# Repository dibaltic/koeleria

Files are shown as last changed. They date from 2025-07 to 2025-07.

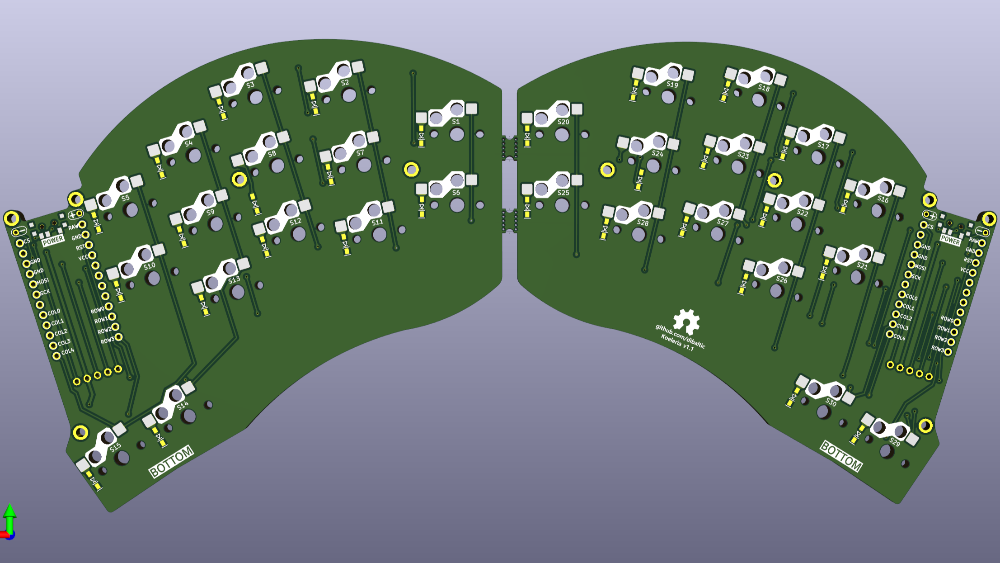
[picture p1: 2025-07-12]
PCB/images/bottomPCB.png

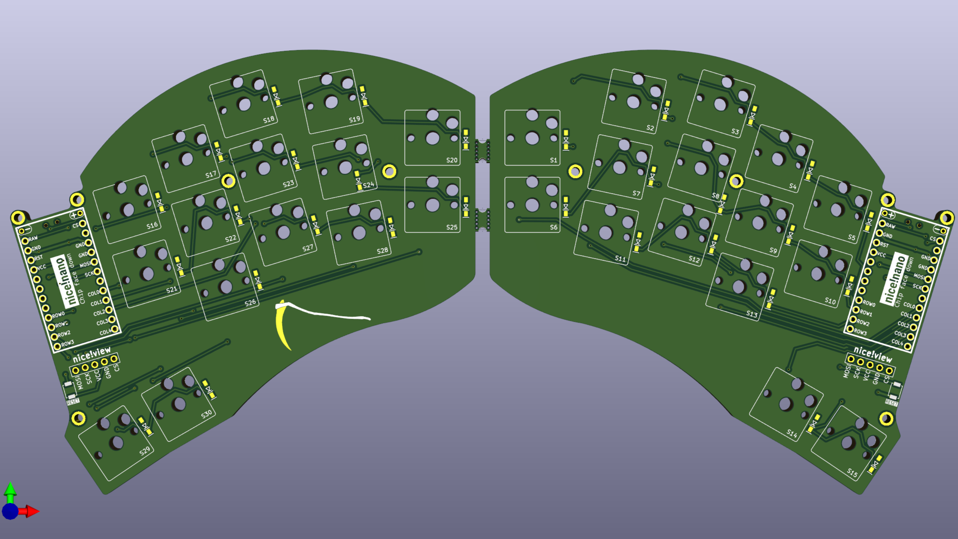
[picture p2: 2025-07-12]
PCB/images/topPCB.png

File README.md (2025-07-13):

# Koeleria
WithWithoutDisplay
CaseAngled

## Features
- 30 keys with splay and column stagger
- nice!view and nice!nano
- Hotswap sockets, no direct solder option for switches
- Low profile Choc V1 switches with Choc spacing
- Exclusively wireless using [ZMK firmware](https://zmk.dev/)
- Cases are designed to be low profile with recessed adhesive feet
- A variety of cases can be found in the [3d_Print](https://github.com/dibaltic/koeleria/tree/main/3d_Print) folder. Including enclosed split, minimal split, unibody, storage case, and variety of tenting angles.

SideProfile

### Design

- My first ergo keyboard was an MX Sweep, and then shortly after a wireless Choc Sweep. I wanted my thumbs less tucked, to use my pinky less, and reach less with my index finger. I also wanted to have the option for a display. 

- My goal was to make keyboard to be as low profile as I could. The case adds 1mm in height to the PCB. There is a total of 1.5mm added height with the specified silicone feet installed on the case.

- In the majority of the photos I am using [KLP Lamé](https://github.com/braindefender/KLP-Lame-Keycaps) keycaps with LSDA profile thumbs, but the case was designed around clearing normal keycaps as you can see in the photos of the unibody case with a full set LSDA keycaps installed.

- All the files for the keyboard and cases have been shared if you would like to modify anything to better suit your needs.

MinimalAndEnclosed

# B.O.M 

#### Required

- 1x PCB pair (production files can be found [here](https://github.com/dibaltic/koeleria/tree/main/PCB/Gerbers))
- 30x Kailh Choc V1 switches
- 30x Key caps
- 30x Kailh Choc hotswap sockets (no direct switch soldering support)
- 30x SMD diodes 1n4148w (SOD-123)
- 2x nice!nano
- 2x batteries (301230)
- 2x female headers (mcu sockets)
- 48x header pins (mill-max or other solution)

#### Optional

- 2× nice!view
- 2× Reset switch (B3U-1000P(M))
- 2× Power switch (MSK 12C02)
- 10× adhesive silicone feet 8mmx2.5mm
> Note: If you are using a case from [3d_Print folder](https://github.com/dibaltic/koeleria/tree/main/3d_Print) you will need M2 hardware, heatserts, and additional non-slip feet. More information can be found in the corresponding readme.

# Firmware

- [zmk_koeleria](https://github.com/dibaltic/zmk_koeleria)

# Pictures
  
UnibodyAndSplit

StorageCase

StorageCase3

MinimalSide

# Inspirations and Credit
I took inspiration from the [Urchin](https://github.com/duckyb/urchin), [Sweep](https://github.com/davidphilipbarr/Sweep), and [Luna](https://github.com/mindhatch/keyboards). I used footprints from the Urchin, and used [ergogen](https://ergogen.ceoloide.com/) to get the physical key placement configured before designing the rest in Kicad and Freecad.

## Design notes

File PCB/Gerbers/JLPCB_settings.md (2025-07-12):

## Recommended settings to order the PCB 
- Base Material- FR-4
- Layers-  2
- PCB QTY- 5 -> your choice
- Different Design- 2
- Delivery Format- Single PCB
- PCB Thickness- 1.6
- PCB Color- Personal preference
- Silkscreen- Personal preference
- Surface Finish- Personal preference
- Outer Copper Weight- 1oz
- Confirm Production file- No
- Mark on PCB- Personal preference
- Gold Fingers- No
- Castellated Holes- No
- Edge Plating- No

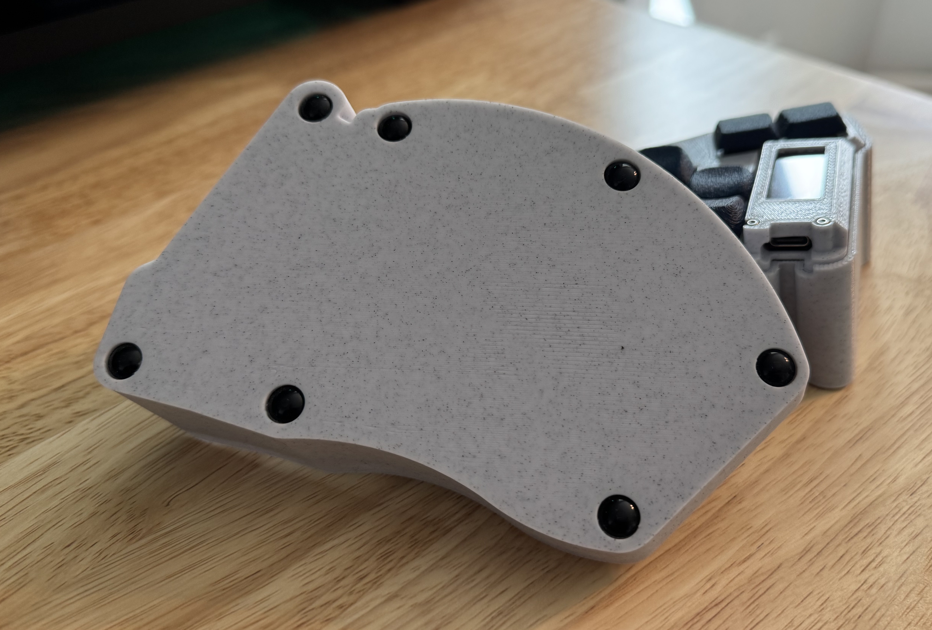
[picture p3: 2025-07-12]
gallery/TentingBottom.jpg

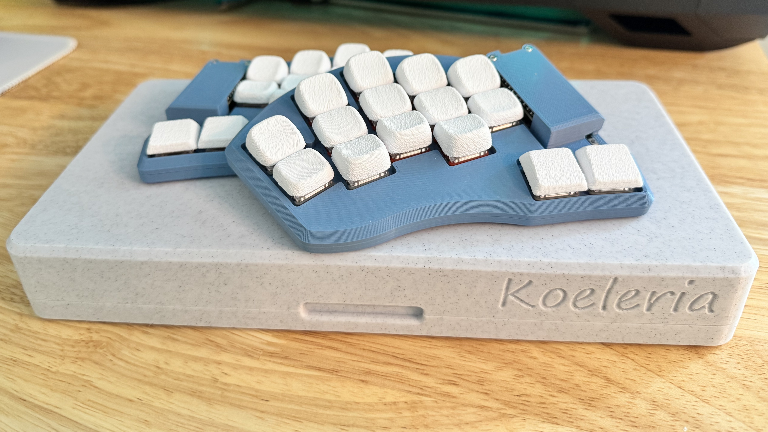
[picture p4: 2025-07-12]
gallery/StorageCase.jpg

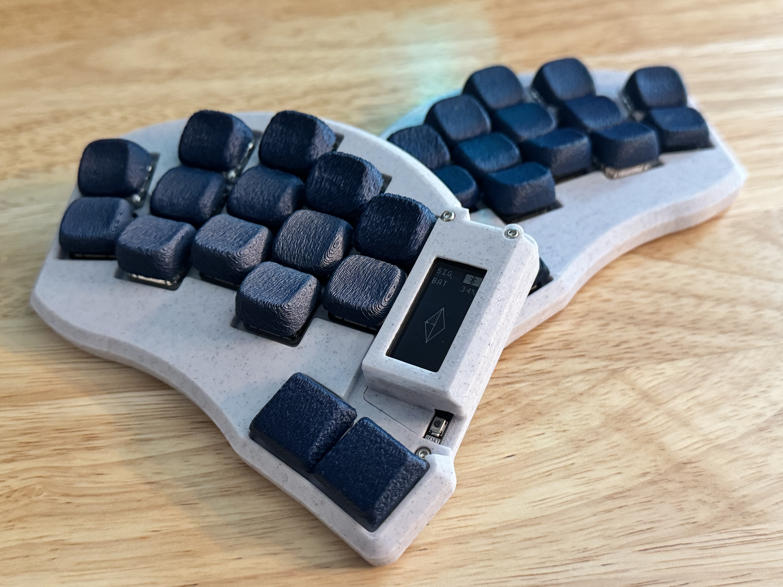
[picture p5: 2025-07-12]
gallery/CaseAngled.jpg

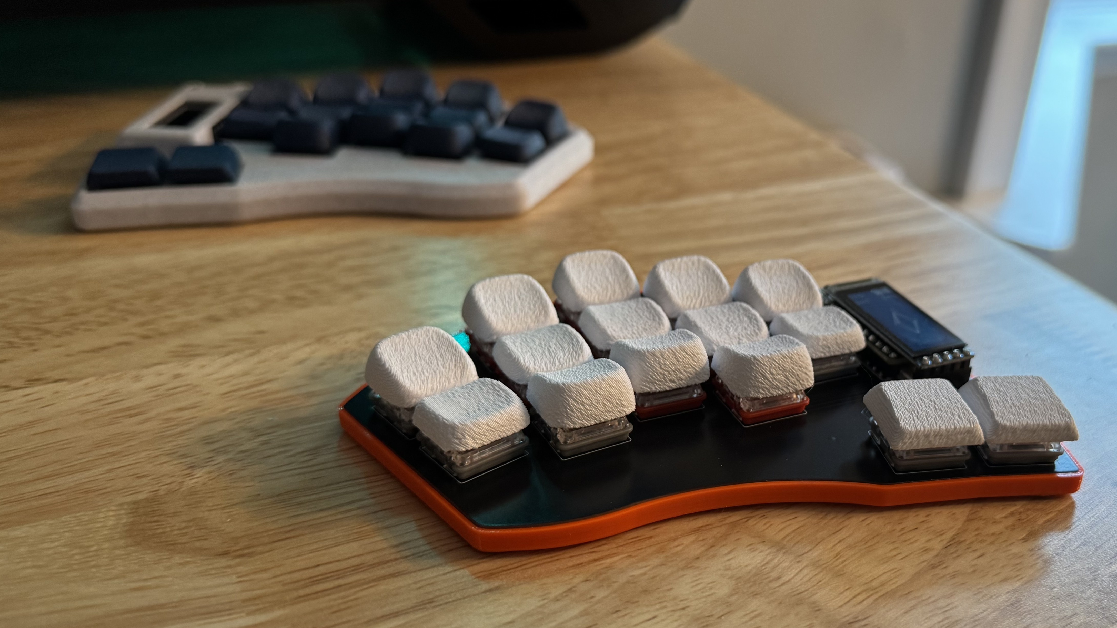
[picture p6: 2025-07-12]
gallery/MinimalSide.jpg

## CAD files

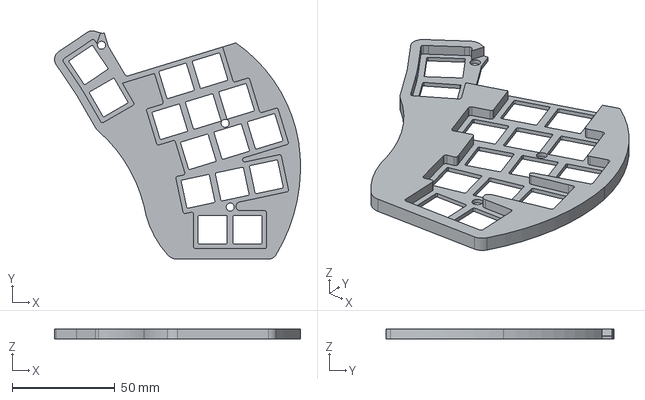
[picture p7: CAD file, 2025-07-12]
3d_Print/CaseSplitEnclosed/Step/RightLid.step
119.7 x 111.1 x 5.10 mm

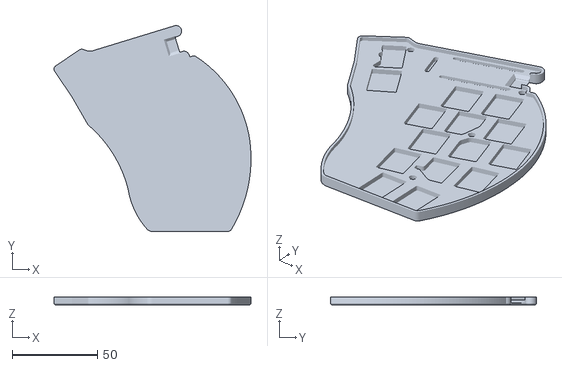
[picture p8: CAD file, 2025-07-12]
3d_Print/MinimalCase/Print/Right.stl
115.3 x 120.5 x 4.60

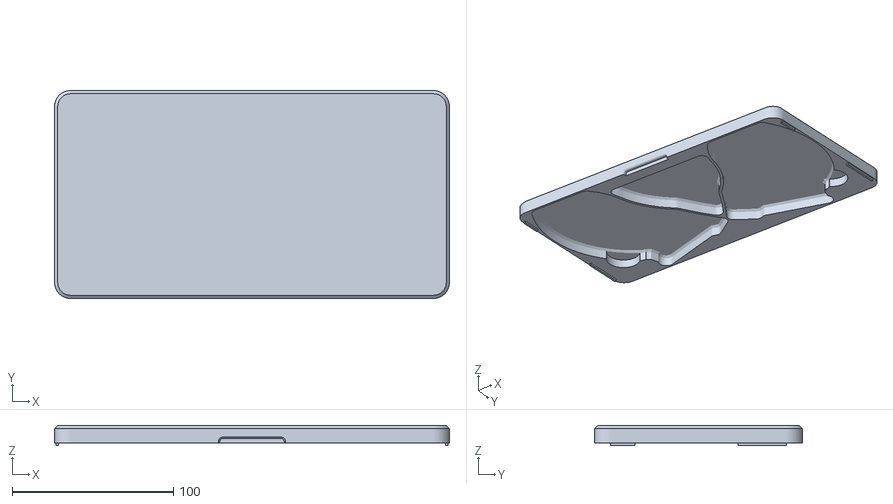
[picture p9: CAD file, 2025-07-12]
3d_Print/StorageCase/Print/bottom.stl
244.9 x 129.0 x 12.5

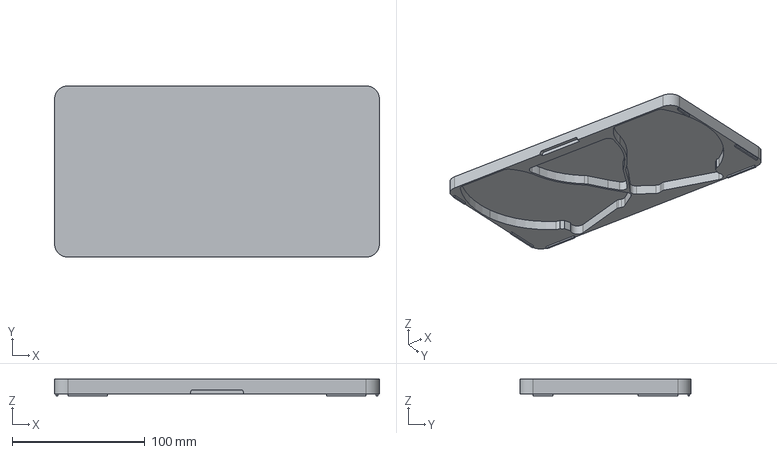
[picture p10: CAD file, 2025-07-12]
3d_Print/StorageCase/Step/KeyboardCase-case bottom.step
244.9 x 129.0 x 12.4 mm

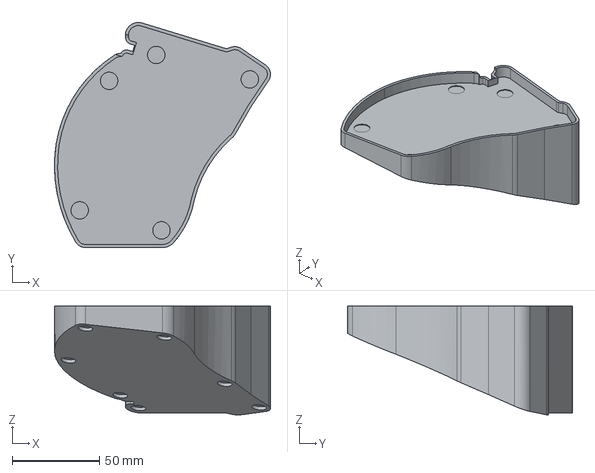
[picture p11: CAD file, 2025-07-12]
3d_Print/Tenting/Step/tenting20degreeLeft.step
123.7 x 129.0 x 62.4 mm

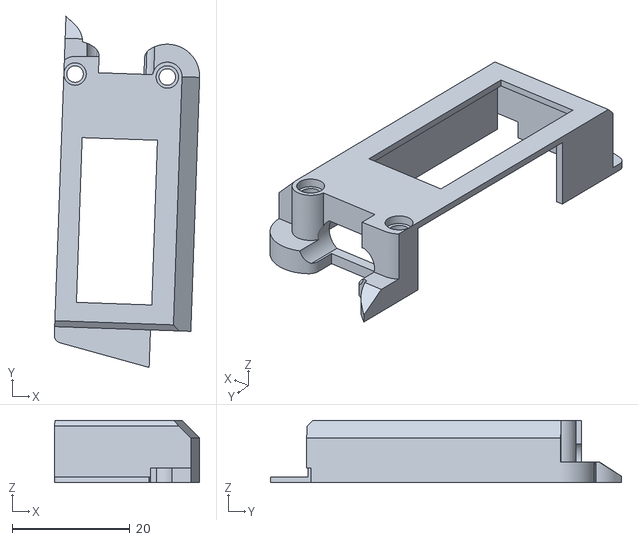
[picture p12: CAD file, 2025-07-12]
3d_Print/Unibody/Print/LeftMcuCoverChamfer.stl
24.7 x 59.6 x 10.6

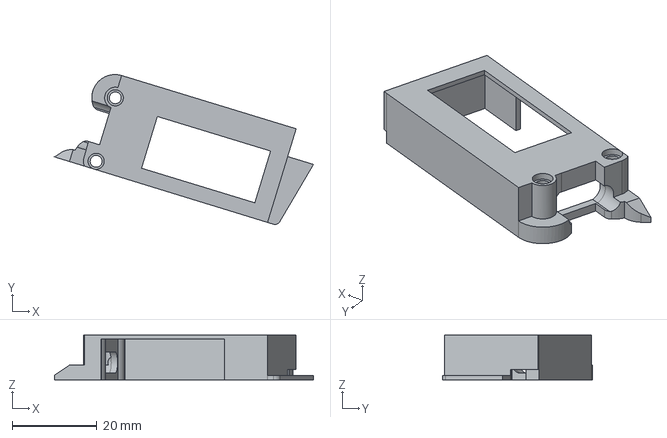
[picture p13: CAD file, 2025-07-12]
3d_Print/Unibody/Step/LeftMCUCover.step
61.3 x 35.5 x 10.6 mm

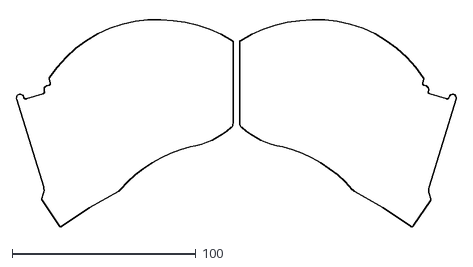
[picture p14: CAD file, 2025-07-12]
PCB/edge_cuts.dxf
239.9 x 114.7

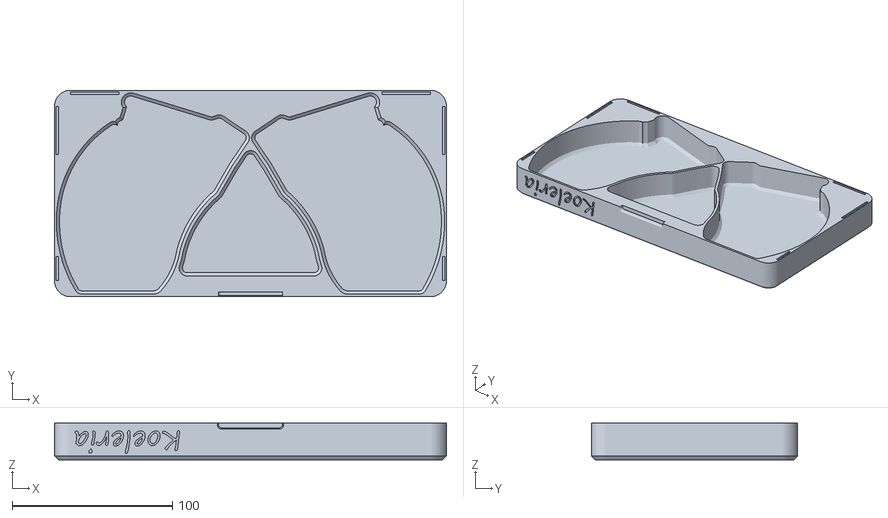
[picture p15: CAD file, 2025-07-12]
3d_Print/StorageCase/Print/lid.stl
244.9 x 129.0 x 23.0

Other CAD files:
3d_Print/MinimalCase/Step/RightMinimal.step
3d_Print/MinimalCase/Print/Left.stl
3d_Print/MinimalCase/Step/MinimalLeft.step
3d_Print/StorageCase/Step/KeyboardCase-lid.step
3d_Print/Tenting/Step/tenting20degreeRight.step
3d_Print/Unibody/Print/RightLidChamfer.stl
3d_Print/CaseSplitEnclosed/Step/LeftLid.step
3d_Print/CaseSplitEnclosed/Print/LeftBottom.stl
3d_Print/CaseSplitEnclosed/Print/RightBottom.stl
3d_Print/CaseSplitEnclosed/Step/LeftBottom.step
3d_Print/CaseSplitEnclosed/Step/RightBottom.step
3d_Print/Tenting/Print/tenting12degreeLeft.stl
3d_Print/Tenting/Print/tenting12degreeRight.stl
3d_Print/Tenting/Print/tenting20degreeLeft.stl
3d_Print/Tenting/Print/tenting20degreeRight.stl
3d_Print/Tenting/Print/tenting7degreeLeft.stl
3d_Print/Tenting/Print/tenting7degreeRight.stl
3d_Print/Tenting/Step/tenting12degreeLeft.step
3d_Print/Tenting/Step/tenting12degreeRight.step
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

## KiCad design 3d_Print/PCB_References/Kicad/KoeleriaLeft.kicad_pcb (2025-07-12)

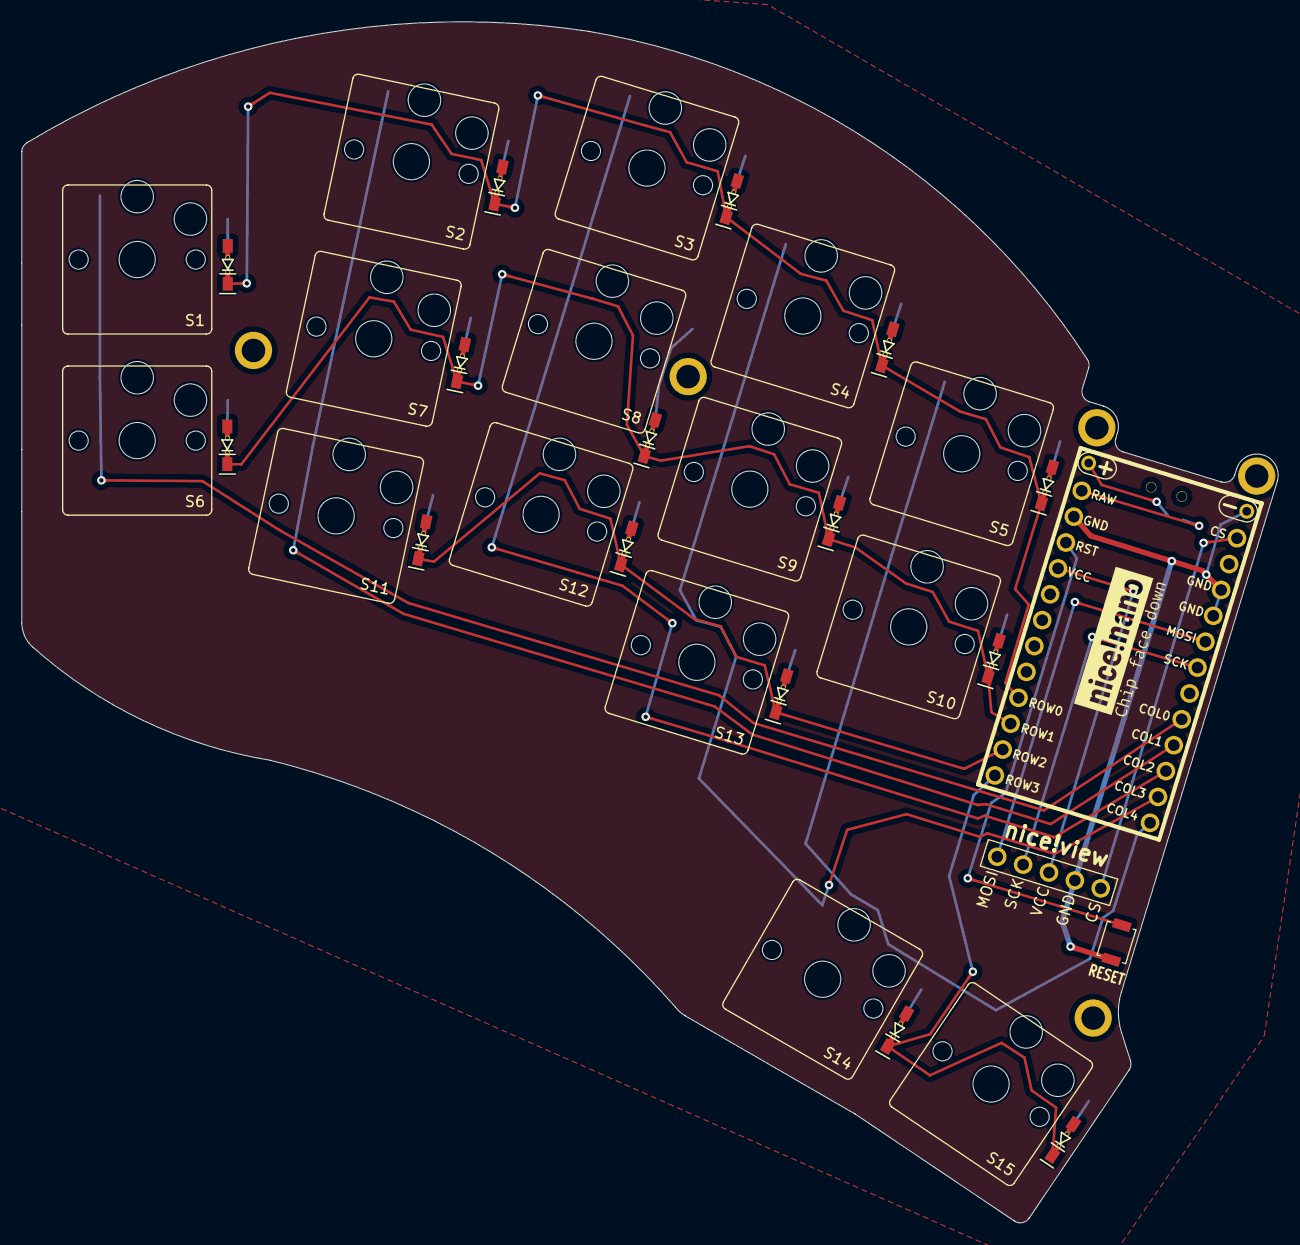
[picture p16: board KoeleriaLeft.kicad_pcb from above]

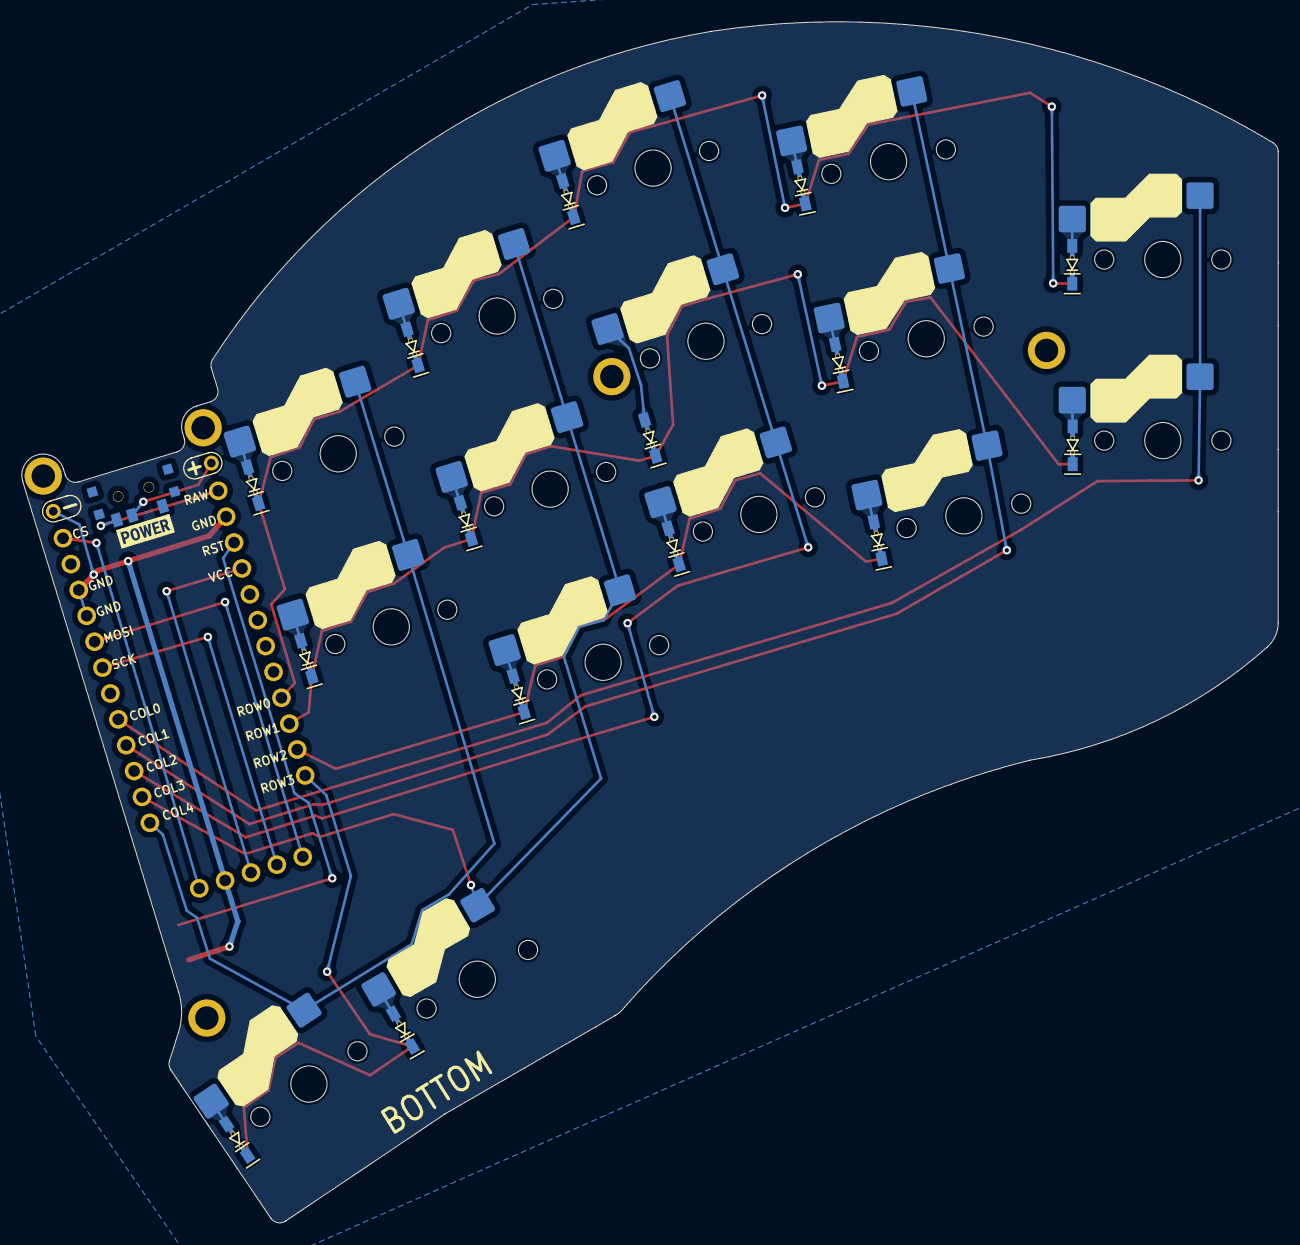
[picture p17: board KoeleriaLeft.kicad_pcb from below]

Board: 2 copper layers, 118.0 x 112.8 mm, 39 parts (18 on the bottom side), 15 nets.

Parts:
Bat+0, Bat+0#2: MountingHole_Pad; ducky_1pin_Battery
D1, D2, D3, D5, D6, D7, D8, D9, D10, D11, D12, D13, D14, D15: ducky_diode
D4: duckey diode
DISP1: ducky_nice_view
RESET: SW_SPST_B3U-1000P
S1, S2, S3, S4, S5, S6, S7, S8, S9, S10, S11, S12, S13, S14, S15: ducky_Hotswap_Kailh_Choc_V1_tweaked
SW_POWER1: SW_SPDT; smt-slider-switch
U2: nice_nano; ducky_nice_nano
kibuzzard-636588C8: G***; kibuzzard-636588C8
kibuzzard-6365884B: G***; kibuzzard-6365884B
kibuzzard-6365951E: G***; kibuzzard-6365951E

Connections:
index_bottom: D9.2, S6.2
index_home: D10.2, S11.2
index_top: D11.2, S12.2
inner_bottom: D12.2, S13.2
inner_home: D13.2, S10.2
inner_thumb: D14.2, S14.2
middle_bottom: D6.2, S8.2
middle_home: D7.2, S9.2
middle_top: D8.2, S5.2
pinky_home: D1.2, S2.2
pinky_top: D2.2, S3.2
ring_bottom: D3.2, S4.2
ring_home: D4.2, S1.2
ring_top: D5.2, S7.2
space_thumb: D15.2, S15.2

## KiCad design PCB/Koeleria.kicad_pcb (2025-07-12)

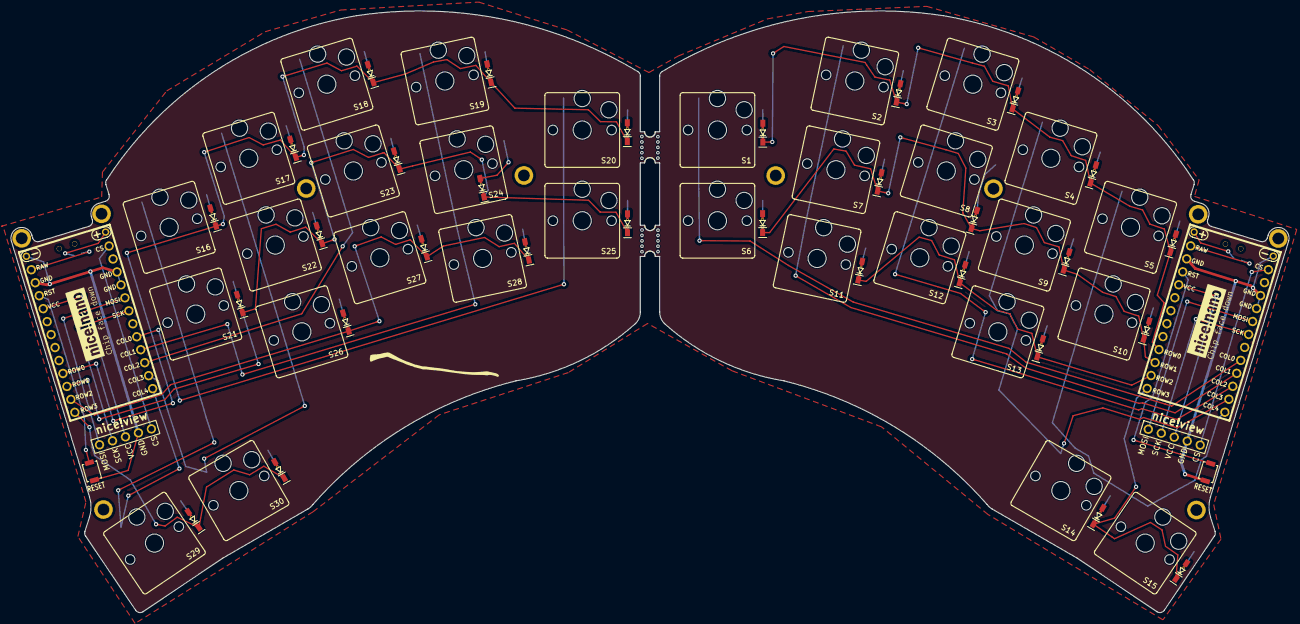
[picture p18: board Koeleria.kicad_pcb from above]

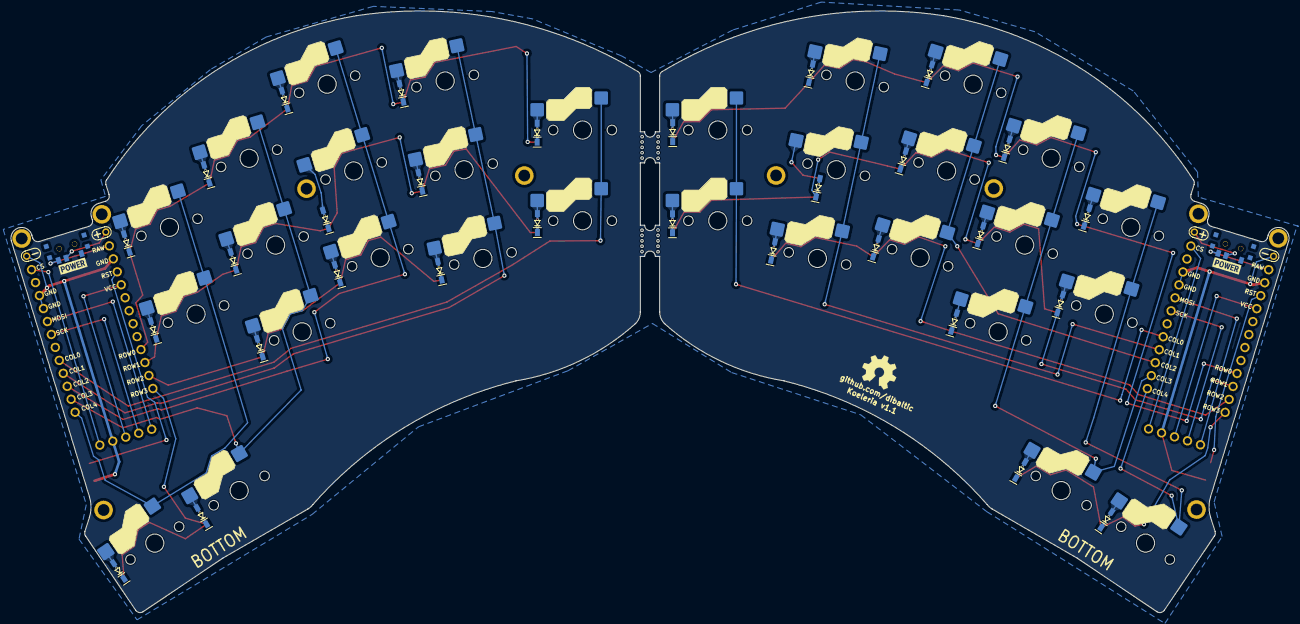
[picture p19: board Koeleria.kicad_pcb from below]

Board: 2 copper layers, 239.5 x 112.8 mm, 80 parts (36 on the bottom side), 30 nets.

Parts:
Bat+0, Bat+0#2, Bat+0#3, Bat+0#4: MountingHole_Pad; ducky_1pin_Battery
D1, D2, D3, D5, D6, D7, D8, D9, D10, D11, D12, D13, D14, D15, D16, D17, D19, D20, D21, D22, D23, D24, D25, D26, D27, D28, D29, D30: ducky_diode
D4, D18: duckey diode
DISP1, DISP1#2: ducky_nice_view
RESET: SW_SPST_B3U-1000P
RESET#2: SW_SPST_B3U-1000P
S1, S2, S3, S4, S5, S6, S7, S8, S9, S10, S11, S12, S13, S14, S15, S16, S17, S18, S19, S20, S21, S22, S23, S24, S25, S26, S27, S28, S29, S30: ducky_Hotswap_Kailh_Choc_V1_tweaked
SW_POWER1, SW_POWER1#2: SW_SPDT; smt-slider-switch
U2, U2#2: nice_nano; ducky_nice_nano
kibuzzard-636588C8, kibuzzard-636588C8#2: G***; kibuzzard-636588C8
kibuzzard-6365884B, kibuzzard-6365884B#2: G***; kibuzzard-6365884B
kibuzzard-6365951E, kibuzzard-6365951E#2: G***; kibuzzard-6365951E
mouse-bite-2mm-slot, mouse-bite-2mm-slot#2: VAL**; mouse-bite-5mm-slot-with-space-for-track

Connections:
index_bottom: D9.2, S6.2
index_home: D10.2, S11.2
index_top: D11.2, S12.2
inner_bottom: D12.2, S13.2
inner_home: D13.2, S10.2
inner_thumb: D14.2, S14.2
middle_bottom: D6.2, S8.2
middle_home: D7.2, S9.2
middle_top: D8.2, S5.2
mirror_index_bottom: D24.2, S25.2
mirror_index_home: D25.2, S28.2
mirror_index_top: D26.2, S27.2
mirror_inner_bottom: D27.2, S26.2
mirror_inner_home: D28.2, S21.2
mirror_inner_thumb: D29.2, S30.2
mirror_middle_bottom: D21.2, S23.2
mirror_middle_home: D22.2, S22.2
mirror_middle_top: D23.2, S16.2
mirror_pinky_home: D16.2, S19.2
mirror_pinky_top: D17.2, S18.2
mirror_ring_bottom: D18.2, S17.2
mirror_ring_home: D19.2, S20.2
mirror_ring_top: D20.2, S24.2
mirror_space_thumb: D30.2, S29.2
pinky_home: D1.2, S2.2
pinky_top: D2.2, S3.2
ring_bottom: D3.2, S4.2
ring_home: D4.2, S1.2
ring_top: D5.2, S7.2
space_thumb: D15.2, S15.2

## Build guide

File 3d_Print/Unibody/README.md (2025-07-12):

# Unibody Case Pictures
Unibody
UnibodyAndSplit

# Features
- Enclosed MCU with 3d files supporting use of displays and no displays
- Snap on top shell/plate, with PCB threaded into lower shell
- Low profile case, with the anti-slip feet installed, the case adds 1.5mm to the height of the PCB
- Recessed anti-slip feet to maintain low profile
- Two print file options for lower shell, with name or blank without name printed on the shell
- Top shells and MCU enclosures are the same as the split body case

# Hardware
These are non-affiliate amazon links to the hardware I used in my builds.

[M2 Bolts](https://www.amazon.com/Machine-Assorted-Stainless-Assortment-Threaded/dp/B0DFWXRM21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)

[M2 Heatserts](https://www.amazon.com/uxcell-Threaded-Inserts-M2x2-5mm-Printing/dp/B0D9N59N2G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)

11x adhesive silicone feet. 8mm x 2.5mm

# Details
- The M2 hardware linked is a variety of sizes. I used 7 inch diagonal cutters to trim the bolts to the length needed since none of the variety in the pack is an exact fit. If you do not trim the bolts that are too long it will leave marks on the back of the case.

- Break-off tabs on the PCB will need removed to be flush with the rest of the PCB edge. Remaining pieces from the break-off tabs may make the case not fit correctly.

- To install the brass heatserts, I used my soldering iron to melt the inserts into the case. The case is intended to be as low profile as I could make it, so there are tight tolerances for the depth. Care must be taken to not insert the inserts too far as you will melt through the back. Even if you don't melt through, on lighter filament colors the insert will be visible.

- The 5 pin header for the nice!views should be placed within the outline on the PCB silkscreen. To put the mcu cover on, I suggest putting the opening for the usb-c on first, and then slide the cover down over the nice!view header. I trimmed the pins that are soldered to the nice!views with flush cutters, just the excess that protruded past the solder.

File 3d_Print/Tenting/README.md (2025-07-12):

# Tenting Pictures
TentingSide
TentingBottom
TentingTop

# Features
- Pictured is 12 degrees, but I have included files for 7 degrees, 12 degrees, and 20 degrees variants

- There are recesses in the tenting mount for the feet that are on the keyboard case

- Adequate clearance to use a usb-c to charge the boards while using the tenting mounts

# Hardware
14x silicone self adhesive feet 8mm x 2.5mm

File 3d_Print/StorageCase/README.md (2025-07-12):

# Storage Case Pictures
StorageCase
StorageCase3
StorageCase2

# Features
- Magnetic lid with locating tabs
- Storage cubby

# Hardware
20x [N52 3/16" x 1/8"](https://www.kjmagnetics.com/d32-n52-neodymium-disc-magnet)

# Details
Print will need paused to insert the magnets in both the lid and the bottom shells, the magnets are beneath the surface of the plastic.

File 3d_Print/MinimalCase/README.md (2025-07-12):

# Minimal Case Pictures
MinimalAndEnclosed
MinimalSide

# Features
- Thin minimal case with no switch plate or mcu enclosure
- Low profile case, with the anti-slip feet installed, the case adds 1.5mm to the height of the PCB
- Recessed anti-slip feet to maintain low profile
- PCB secured to case with machine screws
- Support for using clear acrylic LCD cover. Requires the use mobo standoffs or spacers with long screws.

> Note: This case adds the same amount of height as the fully enclosed case adds

# Hardware
These are non-affiliate amazon links to the hardware I used in my builds.

[M2 Bolts](https://www.amazon.com/Machine-Assorted-Stainless-Assortment-Threaded/dp/B0DFWXRM21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)

[M2 Heatserts](https://www.amazon.com/uxcell-Threaded-Inserts-M2x2-5mm-Printing/dp/B0D9N59N2G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)

10x adhesive silicone feet. 8mm x 2.5mm 

# Details
- This is the same case as the fully enclosed version, minus the top shell and less material past the edge of the PCB. The case adds 1mm around the perimeter of the PCB.

- Break-off tabs on the PCB will need removed to be flush with the rest of the PCB edge. Remaining pieces from the break-off tabs may make the case not fit correctly.

- The M2 hardware linked is a variety of sizes. I used 7 inch diagonal cutters to trim the bolts to the length needed since none of the variety in the pack is an exact fit. If you do not trim the bolts that are too long, it will leave marks on the back of the case.

- To install the brass heatserts, I used my soldering iron to melt the inserts into the case. The case is intended to be as low profile as I could make it, so there are tight tolerances for the depth. Care must be taken to not insert the inserts too far as you will melt through the back. Even if you don't melt through, on lighter colors of filament the insert will be visible as seen in the picture above.

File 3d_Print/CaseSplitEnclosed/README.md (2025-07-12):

# Split Case Pictures
CaseTop
SideProfile
CaseBottom

# Features
- Enclosed MCU with 3d files supporting use of displays and no displays
- Snap on top shell/plate, with PCB threaded into lower shell
- Low profile case, with the anti-slip feet installed, the case adds 1.5mm to the height of the PCB
- Recessed anti-slip feet to maintain low profile

# Hardware
These are non-affiliate amazon links to the hardware I used in my builds.

[M2 Bolts](https://www.amazon.com/Machine-Assorted-Stainless-Assortment-Threaded/dp/B0DFWXRM21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)

[M2 Heatserts](https://www.amazon.com/uxcell-Threaded-Inserts-M2x2-5mm-Printing/dp/B0D9N59N2G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)

10x adhesive silicone feet. 8mm x 2.5mm

# Details
- The M2 hardware linked is a variety of sizes. I used 7 inch diagonal cutters to trim the bolts to the length needed since none of the variety in the pack is an exact fit. If you do not trim the bolts that are too long, it will leave marks on the back of the case.

- Break-off tabs on the PCB will need removed to be flush with the rest of the PCB edge. Remaining pieces from the break-off tabs may make the case not fit correctly.

- To install the brass heatserts, I used my soldering iron to melt the inserts into the case. The case is intended to be as low profile as I could make it, so there are tight tolerances for the depth. Care must be taken to not insert the inserts too far as you will melt through the back. Even if you don't melt through, on lighter colors of filament the insert will be visible as seen in the picture above.

- The 5 pin header for the nice!views should be placed within the outline on the PCB silkscreen. To put the mcu cover on, I suggest putting the opening for the usb-c on first, and then slide the cover down over the nice!view header. I trimmed the pins that are soldered to the nice!views with flush cutters, just the excess that protruded past the solder.

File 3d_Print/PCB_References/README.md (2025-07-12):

# These are the Kicad and step files that were used to create the cases, storage case, and tenting options. It is the board separated into left and right halves.
